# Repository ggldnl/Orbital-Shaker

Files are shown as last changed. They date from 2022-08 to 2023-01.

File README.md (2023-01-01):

# Orbital Shaker

I needed something to help me out shaking the ferric chloride, sodium carbonate and acetone trays when making PCBs. You can check out [my guide](https://github.com/ggldnl/pcb_manufacturing.git) to manufacture PCBs at home. It ain't much but it's honest work

This project was born as a sort of remix of [this orbital shaker](https://learn.adafruit.com/crickit-lab-shaker/3d-printing) to adapt the hardware to what I had at the time at hands; I got caught up in it and added many features via software, hardware and redesigning most of the cad files in fusion360, so I think it is safe to say that this is now a project on its own. 

# Contributing and warn for possible bugs
There will probably still be small bugs (surely one in the soft start menu item), feel free to contribute in any way.
As soon as I have time I will rewrite the code from scratch by implementing the menu in my own way and without resorting to external libraries. Another thing to do would be to use custom (maybe animated) characters (https://www.engineersgarage.com/making-custom-characters-on-lcd-using-arduino/).

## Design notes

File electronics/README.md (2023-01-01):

# Electronics

| component | quantity |
|---|---|
| LM2596 DCDC step down | 2 |
| DRV8833 | 1 |
| Arduino nano | 1 |
| 10K Potentiometer | 1 |
| Push button | 3 |
| 1K Resistor | 3 |
| Diode | 1 |
| 16x2 LCD Display | 1 |

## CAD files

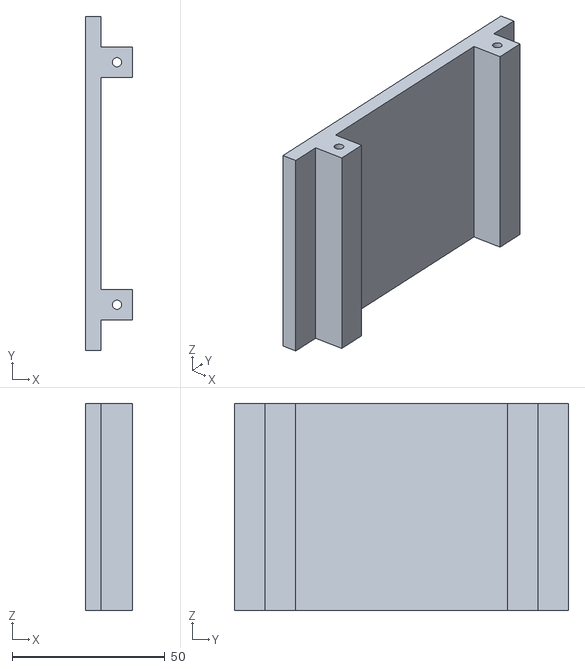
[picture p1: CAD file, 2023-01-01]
cad/left_panel.stl
15.2 x 109.5 x 68.0

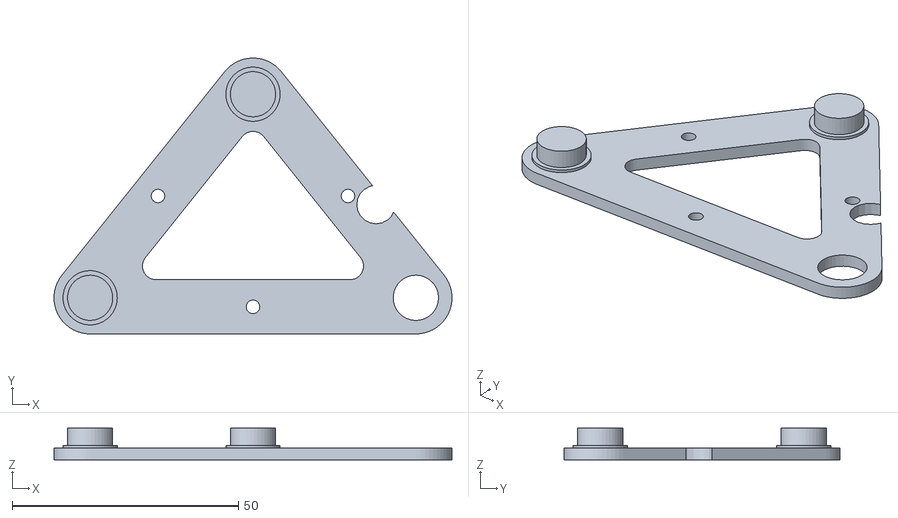
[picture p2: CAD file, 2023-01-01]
cad/bearing_base.stl
88.0 x 61.0 x 7.00

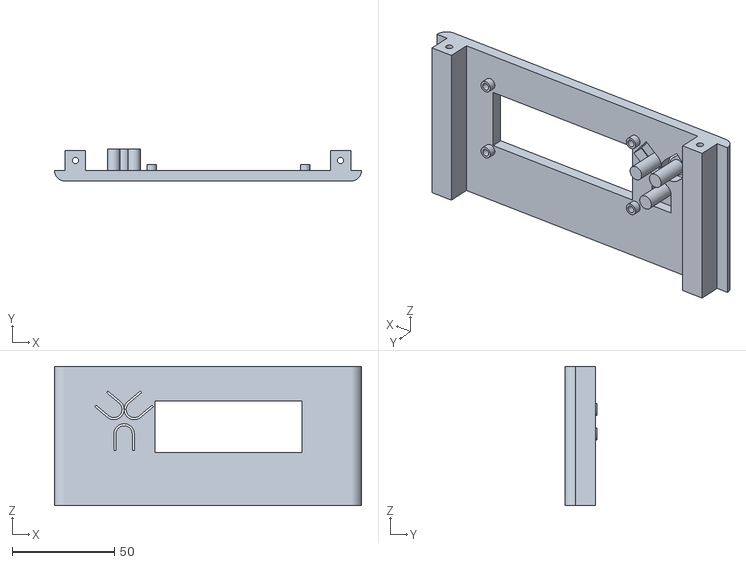
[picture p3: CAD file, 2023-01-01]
cad/front_panel.stl
150.0 x 15.6 x 68.0

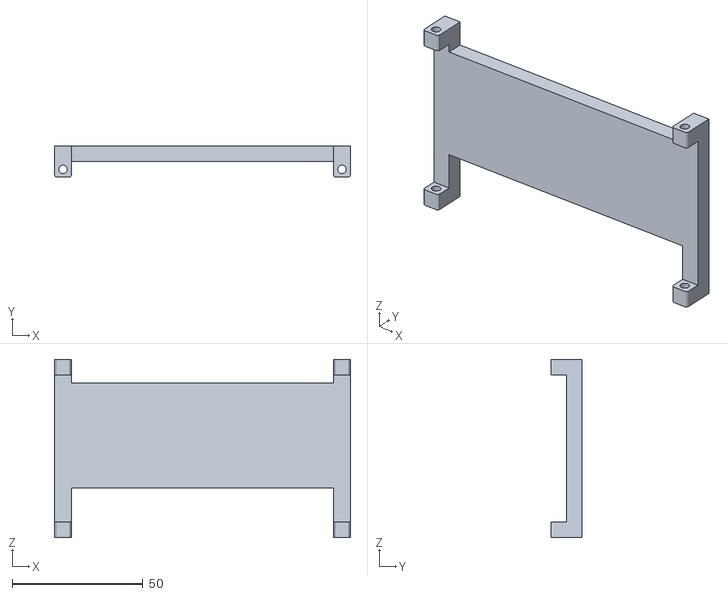
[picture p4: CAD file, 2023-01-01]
cad/display_support.stl
113.0 x 12.0 x 68.0

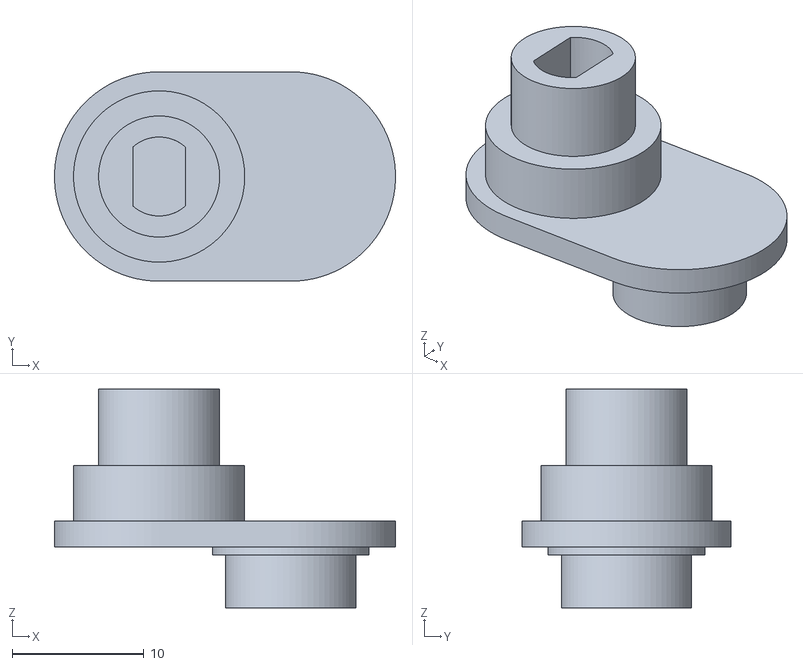
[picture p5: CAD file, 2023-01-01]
cad/motor_hub.stl
25.9 x 15.9 x 16.6

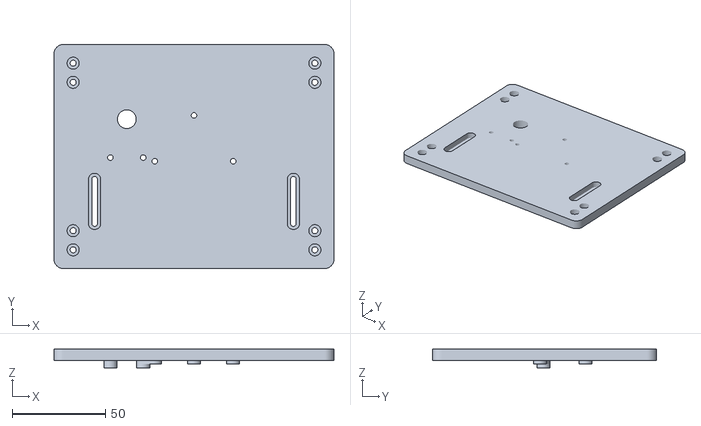
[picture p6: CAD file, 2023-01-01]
cad/top_panel.stl
150.0 x 120.0 x 10.0

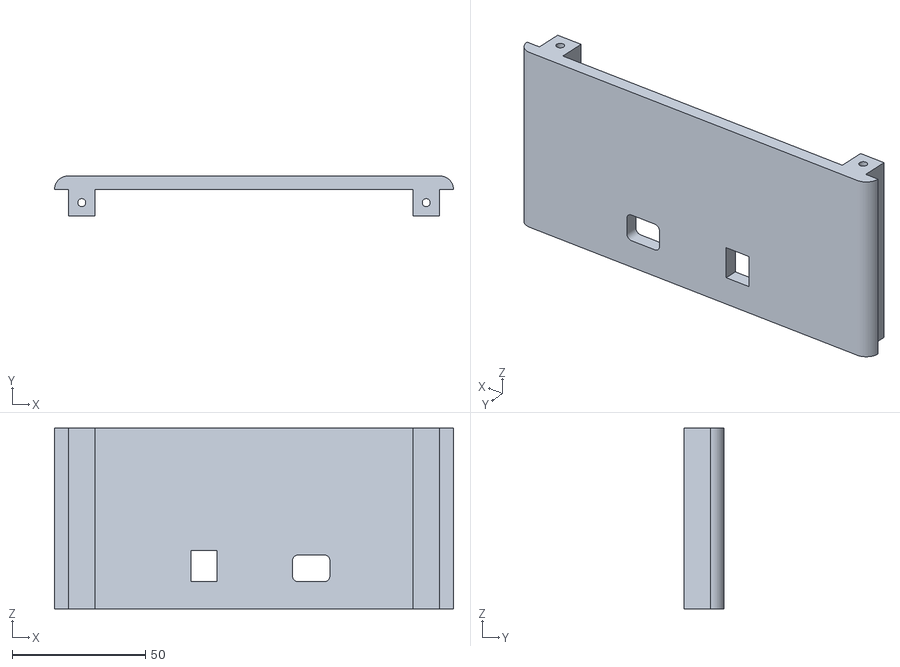
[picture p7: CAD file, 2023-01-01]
cad/back_panel_no_button.stl
150.0 x 15.0 x 68.0

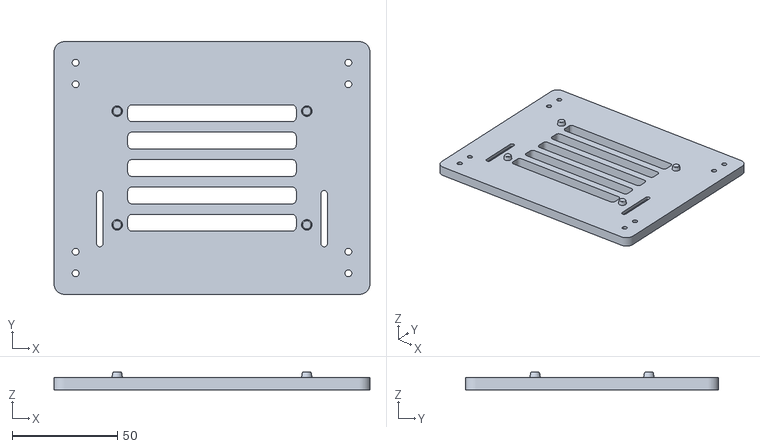
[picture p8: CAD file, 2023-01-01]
cad/bottom_panel.stl
150.0 x 120.0 x 8.50

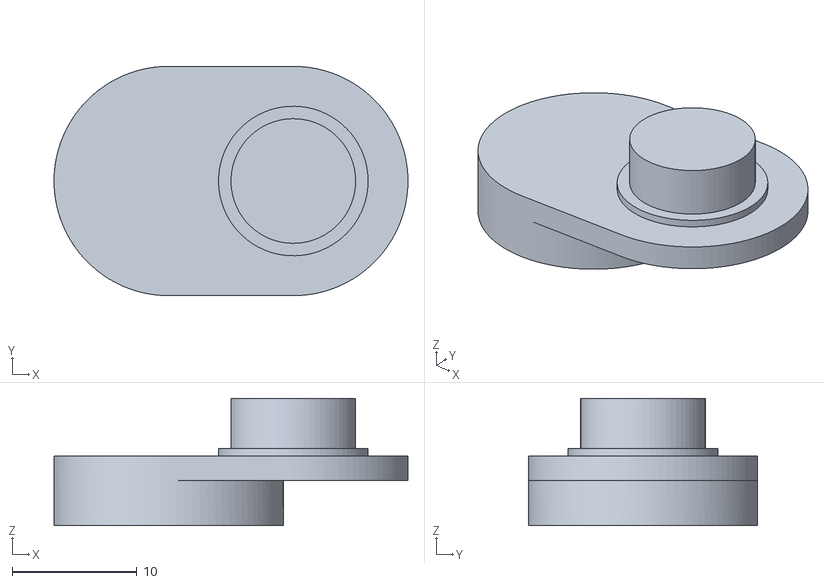
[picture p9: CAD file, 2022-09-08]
cad/idler.stl
28.4 x 18.4 x 10.2

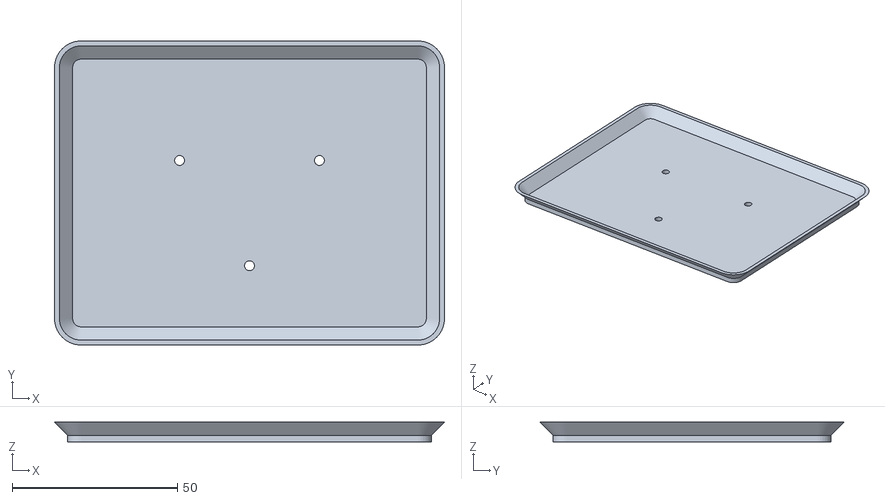
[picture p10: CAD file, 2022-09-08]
cad/tray.stl
118.0 x 92.0 x 6.00

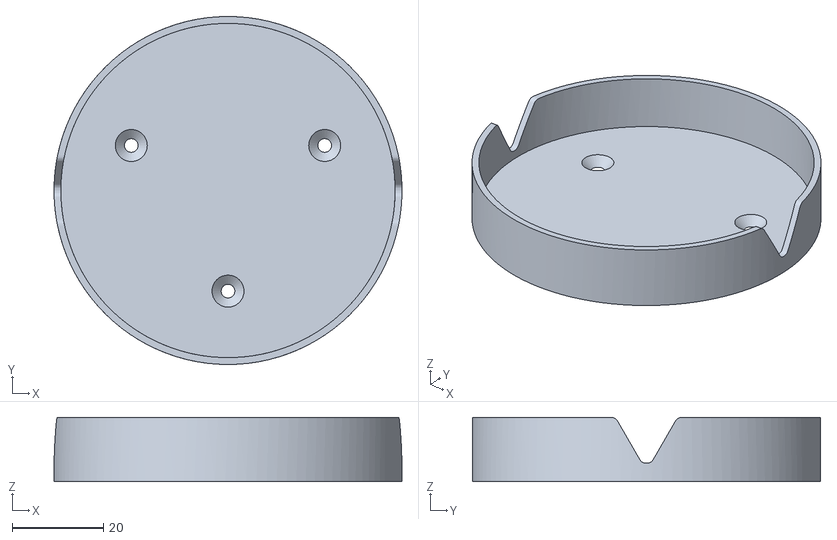
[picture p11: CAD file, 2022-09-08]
cad/holder.stl
76.1 x 76.1 x 14.0

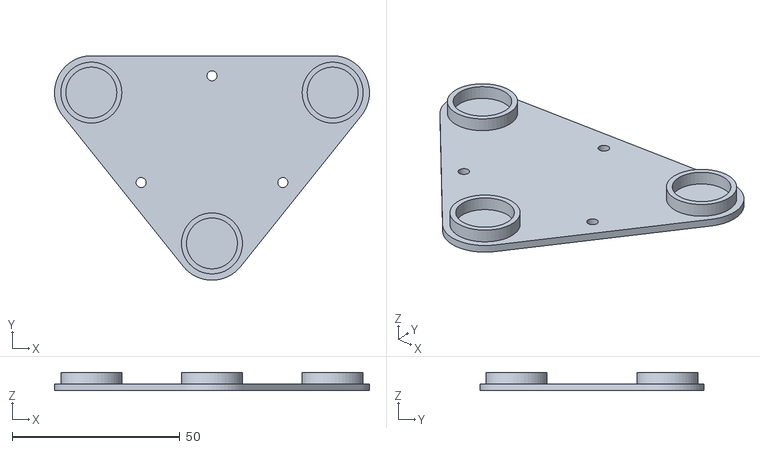
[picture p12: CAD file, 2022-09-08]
cad/plate.stl
94.0 x 67.0 x 5.50

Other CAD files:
cad/right_panel.stl
cad/back_panel_button.stl

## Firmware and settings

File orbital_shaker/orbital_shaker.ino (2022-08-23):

//
// GNU General Public License v3.0
//
// Copyright (C) 2022 Daniel Gigliotti
//
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
/* --------------------------------- pinout --------------------------------- */

/**
 * pins needed for the 1602A LCD screen
 * 
 * VSS -> GND
 * VDD -> +5v
 * V0 -> al potenziometro
 * RS -> D13
 * R/W -> GND
 * E -> A1
 * D0 -> N/C
 * D1 -> N/C
 * D2 -> N/C
 * D3 -> N/C
 * D4 -> Arduino D12
 * D5 -> Arduino D10
 * D6 -> Arduino D9
 * D7 -> Arduino D8
 * A -> Arduino A0
 * K -> GND
 */
#define LCD_RS 13
#define LCD_E  A1
#define LCD_D4 12
#define LCD_D5 11
#define LCD_D6 8
#define LCD_D7 7
#define LCD_A A0

/**
 * we will need 3 push buttons
 * BTN_ENTER -> D4
 * ENC_LEFT -> D5
 * ENC_RIGHT -> D6
 */
#define BTN_ENTER 3
#define BTN_LEFT 4
#define BTN_RIGHT 5
#define PIN_CTRL 6

/**
 * And we will need two PWM pins to drive the motor.
 * The board will be always enabled when current is supplied
 * DRV8833_EEP -> 5V
 * DRV8833_IN1 -> D3
 * DRV8833_IN2 -> D11
 */
#define DRV8833_IN1 10
#define DRV8833_IN2 9

/* -------------------------------- libraries ------------------------------- */

#include <LiquidCrystal.h> // for the LCD
#include "CMBMenu.hpp"

// timer to handle the routine, explained later in mainStart(...) function
#include <Simpletimer.h>

/*
 * Library developed by Kalinin Edward
 * http://mypractic.com/ 
 * Lesson 18. 
 * 
 * I only added a method to check if a pin is enabled or not
 */
#include "MatrixKey.h"
#include <MsTimer2.h> // to use the MatrixKey library: it updates the status periodically

/*
 * Library developed by *me* :)
 */
#include "DRV8833.h"

/* --------------------------------- objects -------------------------------- */

LiquidCrystal lcd(LCD_RS, LCD_E, LCD_D4, LCD_D5, LCD_D6, LCD_D7);

// vertical line -> pin 7
// horizontal line -> 4, 5, 6
// number of confirmations of the status of contacts = 6
MatrixKeys keys (PIN_CTRL, 255, 255, 255, BTN_ENTER, BTN_LEFT, BTN_RIGHT, 255, 6);

DRV8833 motor_driver (DRV8833_IN1, DRV8833_IN2);

/* ---------------------------------- menu ---------------------------------- */

// create global CMBMenu instance
CMBMenu<100> menu; // max 100 menu entries

/**
 * the menu will have this structure:
 *   initial_screen
 *    back
 *    settings
 *      back
 *      speed
 *      time
 *      change direction (y/n)
 *    start
 */
// PROGMEM -> store the string  into the flash memory
const char main_menu_str[] PROGMEM = {"Orbital Shaker"};
const char main_settings_str[] PROGMEM = {"Settings"};
const char main_start_str[] PROGMEM = {"Start"};
const char settings_speed_str[] PROGMEM = {"Speed"};
const char settings_time_str[] PROGMEM = {"Time"};
const char settings_direction_str[] PROGMEM = {"Change dir"};
const char settings_dir_interval_str[] PROGMEM = {"Change dir int."};
const char settings_soft_start_str[] PROGMEM = {"Soft start"};
const char main_info_str[] PROGMEM = {"Info"};
const char back_str[] PROGMEM = {"Back"};

// define function IDs
enum MenuFID {
  MainMenu,
  MainBack,
  MainSettings,
  MainStart,
  MainInfo,
  SettingsBack,
  SettingsSpeed,
  SettingsTime,
  SettingsDir,
  SettingsDirInterval,
  SettingsSoftStart
};

// define key types
enum KeyType {
  KeyNone, // no key is pressed
  KeyLeft,
  KeyRight,
  KeyEnter
};

void setup_lcd (void) {
  
  pinMode(LCD_A, OUTPUT); // A0
  digitalWrite(LCD_A, HIGH); // LCD turned on

  pinMode(A1, OUTPUT); // E (enable)
  digitalWrite(A1, HIGH);

  // (rows, cols)
  lcd.begin(16, 2);

  delay(500);
  lcd.print("Sup bitch");
  delay(1000);
  lcd.clear();
}

void setup_keypad (void) {
  MsTimer2::set(2, timerInterrupt); // set the timer interrupt period 2 ms
  MsTimer2::start(); // enable timer interrupt  
}

void setup_motor_driver (void) {
  motor_driver.hardware_setup(); // All done inside the library, poor design choices YOLOOOO
}

void timerInterrupt() {
  keys.scanState(); // scan matrix
}

/* -------------------------------- variables ------------------------------- */

/*
 * Timer0 is used for micros(), millis(), delay(), etc and can't be used
 * Timer1 is used to generate hardware pwm for the DRV8833 board
 * Timer2 is used for the keypad
 * 
 * since the timing doesn't have to be precise for the routine (the error is in the order of ms,
 * while once the job starts it can last several minutes) we can simply use millis() and so on
 * in the main loop to check if the job needs to be terminated or not.
 * The library SimpleTimer internally uses millis() and micros()
 */
bool job_running = false;
long running_time = 0;
Simpletimer jobTimer; // timer to handle the whole procedure

const int update_interval = 1000; // 1000 ms
long starting_time = 0;
long elapsed_time = 0;
long job_percent = 0;
Simpletimer lcdUpdateTimer; // timer to update the percentage on the lcd

// job duration
int time_m = 10; // standard job duration
int time_delta = 1;
int min_time = 1;
int max_time = 60;

// speed
int current_speed = 50;
const int speed_delta = 10;
int min_speed = 10;
int max_speed = 100;

// soft start
Simpletimer softStartTimer; // timer to increase speed for a soft start
bool soft_start = true;
int soft_start_speed = 10;
int soft_start_delta = 5;

// change direction
Simpletimer changeDirTimer; // timer to periodically change direction
bool change_dir = true;
int min_dir_interval = 1; // 1 minute
int change_dir_delta = 1;
long change_dir_interval = min_dir_interval;

void setup() {
  
  // open the serial line
  Serial.begin(115200);

  // setup all the stuff
  setup_lcd();
  setup_keypad();
  setup_motor_driver();

  // add nodes to menu (layer, string, function ID)
  menu.addNode(0, main_menu_str , MainMenu);
  menu.addNode(1, main_start_str, MainStart);
  menu.addNode(1, main_settings_str, MainSettings);
  menu.addNode(2, settings_time_str, SettingsTime);
  menu.addNode(2, settings_speed_str, SettingsSpeed);
  menu.addNode(2, settings_direction_str, SettingsDir);
  menu.addNode(2, settings_dir_interval_str, SettingsDirInterval);
  menu.addNode(2, settings_soft_start_str, SettingsSoftStart);
  menu.addNode(2, back_str, SettingsBack);
  menu.addNode(1, back_str, MainBack);
  menu.addNode(1, main_info_str, MainInfo);

  // build menu
  const char* info;
  menu.buildMenu(info);

  // print current menu entry
  printMenuEntry(info);
}

void loop() {

  // function ID
  int fid = 0;

  // info text from menu
  const char* info;

  // go to deeper or upper layer?
  bool layerChanged = false;

  // determine pressed key
  KeyType key = getKey();

  // call menu methods regarding pressed key
  switch(key) {
    case KeyEnter:
      menu.enter(layerChanged);
      break;
    case KeyRight:
      menu.right();
      break;
    case KeyLeft:
      menu.left();
      break;
    default:
      break;
  }

  // pint/update menu when key was pressed
  // and get current function ID "fid"
  if (key != KeyNone) {
    fid = menu.getInfo(info);
    printMenuEntry(info);
  }

  // do action regarding function ID "fid"

  if ((fid != 0) && (KeyEnter == key) && (!layerChanged)) {
    switch (fid) {
      
      case MainBack:
      case SettingsBack:

        back(info);
        break;

      case MainStart:
        mainStart(info);
        break;

      case SettingsSpeed:

        /*
         * we are now stuck in another cycle until enter is pressed again
         */
        settingsSpeed (info);
        break;

      case SettingsTime:

        settingsTime (info);
        break;

      case SettingsDir:

        settingsDir (info);
        break;

      case SettingsSoftStart:

        settingsSoftStart(info);
        break;

      case SettingsDirInterval:

        settingsDirInterval(info);
        break;

      case MainInfo:

        mainInfo (info);
        break;

      default:
        break;
    }
  }

  if (job_running && jobTimer.timer(running_time)){
    callback();
    job_running = false;
    printLines("Job done", "100 %");
    keys.enable();
    
    Serial.print("Job ended after ");
    Serial.print(running_time / 1000);
    Serial.println(" milliseconds");
  }

  /*
   * soft start starts from min speed and increases it until reaching
   * user input speed
   */
  if (job_running && soft_start && softStartTimer.timer(1000)) {
    if (soft_start_speed + soft_start_delta <= current_speed) {
      soft_start_speed += soft_start_delta;
      motor_driver.set_speed(soft_start_speed);

      Serial.print("Speed increased: ");
      Serial.print(soft_start_speed);
      Serial.print(" -> ");
      Serial.print(current_speed);
      Serial.println();
    }
  }

  if (job_running && lcdUpdateTimer.timer(update_interval)) {
    // percent : 100 = elapsed : total
    // percent = (elapsed * 100) / total
    // total = running_time
    elapsed_time = millis() - starting_time;
    job_percent = (elapsed_time * 100) / running_time;
    printLines("Job running...", String(job_percent) + " %");

    Serial.print("Elapsed time: ");
    Serial.print(elapsed_time);
    Serial.println(" ms");

    //Serial.print("Current job percent: ");
    //Serial.print(job_percent);
    //Serial.println(" %");
  }

  if (job_running && change_dir && changeDirTimer.timer(change_dir_interval * 60 * 1000)) {
    motor_driver.halt();
    delay(500); // so the motor doesn't complain
    motor_driver.invert_direction();

    Serial.println("Swapping direction");
  }
}

/* ---------------------------- utility functions --------------------------- */

/*
 * prints the menu entry on the LCD display
 */
void printMenuEntry(const char* f_Info) {

  String info_s;
  MBHelper::stringFromPgm(f_Info, info_s);

  // print on LCD
  lcd.clear();
  lcd.setCursor(0, 0);
  lcd.print(info_s);
}

KeyType getKey() {
  
  KeyType key = KeyNone;

  // MatrixKeys keys (PIN_CTRL, 255, 255, 255, BTN_ENTER, BTN_LEFT, BTN_RIGHT, 255, 6);
  // BTN_ENTER -> 0
  // BTN_LEFT -> 1
  // BTN_RIGHT -> 2
  if (keys.flagClick[0][0] == true) {
    keys.flagClick[0][0] = false; // consume the click
    key = KeyEnter;
    Serial.println("Pressed: Enter");
  } else if (keys.flagClick[0][1] == true) {
    keys.flagClick[0][1] = false;
    key = KeyLeft;
    Serial.println("Pressed: Left");
  } else if (keys.flagClick[0][2] == true) {
    keys.flagClick[0][2] = false;
    key = KeyRight;
    Serial.println("Pressed: Right");
  }

 return key;
}

/*
 * clears the lcd and prints the strings, one on each line
 */
void printLines (String str1, String str2) {
  
  lcd.clear();
  lcd.setCursor(0, 0);
  lcd.print(str1);
  lcd.setCursor(0, 1);
  lcd.print(str2);  
}

void printLines (String str, int value) {

  lcd.clear();
  lcd.setCursor(0, 0);
  lcd.print(str);
  lcd.setCursor(0, 1);
  lcd.print(value);
}

/* ----------------------------- menu functions ----------------------------- */

void back (const char*& info) {
  
  // if the action is "back", then go back duh wtf
  menu.exit();
  
  // update the menu
  menu.getInfo(info);
  printMenuEntry(info);
}

void mainInfo(const char*& info) {

  printLines("Info", ">:( go away");

}

/*
 * TODO: store the speed
 */
void settingsSpeed(const char*& info) {

  printLines("Select speed:", current_speed);

  // determine pressed key
  KeyType key;

  while ((key = getKey()) != KeyEnter) {

    if (key == KeyLeft && current_speed - speed_delta >= min_speed) {
      current_speed -= speed_delta;
      printLines("Select speed:", current_speed);
    } else if (key == KeyRight && current_speed + speed_delta <= max_speed) {
      current_speed += speed_delta;
      printLines("Select speed:", current_speed);
    }
  }

  Serial.print("Speed set to ");
  Serial.print(current_speed);
  Serial.println(" %");

  /*
   * at low speed the plate can't move
   */
  current_speed = map(current_speed, min_speed, max_speed, 40, 100);
  
  back(info); // go back and update the menu
}

/*
 * set the spinning time (minutes); 
 * min = 1 minute
 * max = 60 minutes
 * 
 * TODO: store the duration
 */
void settingsTime(const char*& info) {

  printLines("Select time (m):", time_m);

  // determine pressed key
  KeyType key;

  while ((key = getKey()) != KeyEnter) {

    if (key == KeyLeft && time_m - time_delta >= min_time ) {
      time_m-= time_delta;
      printLines("Select time (m):", time_m);
    } else if (key == KeyRight && time_m + time_delta <= max_time) {
      time_m += time_delta;
      printLines("Select time (m):", time_m);
    }
  }

  Serial.print("Time set to ");
  Serial.print(time_m);
  Serial.println(" minute(s)");

  back(info); // go back and update the menu
}

/*
 * change spinning direction each n seconds (default every minute)
 * 
 */
void settingsDir(const char*& info) {

  printLines("Change dir?", change_dir ? "YES" : "NO");

  // determine pressed key
  KeyType key;

  while ((key = getKey()) != KeyEnter) {
    if (key == KeyLeft && change_dir == false) {
      change_dir = true;
      printLines("Change dir?", "YES");
    } else if (key == KeyRight && change_dir == true) {
      change_dir = false;
      printLines("Change dir?", "NO");
    }
  }

  Serial.print("Change dir?");
  Serial.println(change_dir ? "YES" : "NO");

  back(info); // go back and update the menu
}

/*
 * change direction periodically every n minutes/seconds
 */
void settingsDirInterval(const char*& info) {

  printLines("Select interval (m):", change_dir_interval);

  // determine pressed key
  KeyType key;

  while ((key = getKey()) != KeyEnter) {

    if (key == KeyLeft && change_dir_interval - change_dir_delta >= min_dir_interval ) {
      change_dir_interval -= change_dir_delta;
      printLines("Select interval (m):", change_dir_interval);
    } else if (key == KeyRight && change_dir_interval + change_dir_delta <= time_m) {
      change_dir_interval += change_dir_delta;
      printLines("Select time (m):", change_dir_interval);
    }
  }

  Serial.print("Swapping time set to ");
  Serial.print(change_dir_interval);
  Serial.println(" minute(s)");

  back(info); // go back and update the menu
}

/*
 * starts with low speed and slowly increase it
 */
void settingsSoftStart(const char*& info) {

  printLines("Soft start?", soft_start ? "YES" : "NO");

  // determine pressed key
  KeyType key;

  while ((key = getKey()) != KeyEnter) {
    if (key == KeyLeft && soft_start == false) {
      soft_start = true;
      printLines("Soft start", "YES");
    } else if (key == KeyRight && soft_start == true) {
      soft_start = false;
      printLines("Soft start", "NO");
    }
  }

  Serial.print("Soft start?");
  Serial.println(soft_start ? "YES" : "NO");

  back(info); // go back and update the menu
}

void callback(){
  motor_driver.halt();
}

void mainStart (const char*& info) {

  job_running = true;
  running_time = 60 * (long)time_m * 1000; // ms
  starting_time = millis();

  keys.disable();

  if (soft_start)
    motor_driver.forward(current_speed);
  else
    motor_driver.forward(min_speed);
  
  Serial.print("Starting job (");
  Serial.print(running_time);
  Serial.println(") ms");
}

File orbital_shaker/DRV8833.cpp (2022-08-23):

#include "DRV8833.h"
#include <TimerOne.h> // PWM generation
#include "Arduino.h"

DRV8833::DRV8833 (int IN_1, int IN_2, int EEP):
  _IN_1(IN_1), _IN_2(IN_2), _EEP(EEP) {}

DRV8833::DRV8833 (int IN_1, int IN_2):
  _IN_1(IN_1), _IN_2(IN_2), _EEP(255) {}

/*
 * forward:
 * 1   pwm   forward, slow decay
 * pwm   0   forward, fast decay
 */
void DRV8833::forward (float speed_percent) {

  _input_speed = speed_percent;
  _pwm = get_pwm(speed_percent);
  _direction = Direction::FORWARD;

  if (this -> _decay_mode == Decay::SLOW_DECAY) {
    digitalWrite(_IN_1, HIGH);
    Timer1.pwm(_IN_2, _pwm);
  } else {
    Timer1.pwm(_IN_1, _pwm);
    digitalWrite(_IN_2, LOW);
  }
}

/*
 * bacward:
 * pwm   1   backward, slow decay
 * 0   pwm   backward, fast decay
 */
void DRV8833::backward (float speed_percent) {

  _input_speed = speed_percent;
  _pwm = get_pwm(speed_percent);
  _direction = Direction::BACKWARD;

  if (this -> _decay_mode == Decay::SLOW_DECAY) {
    Timer1.pwm(_IN_1, _pwm);
    digitalWrite(_IN_2, HIGH);
  } else {
    digitalWrite(_IN_2, LOW);
    Timer1.pwm(_IN_2, _pwm);
  }
}

void DRV8833::halt () {

  Timer1.pwm(_IN_1, 0);
  Timer1.pwm(_IN_2, 0);
}

void DRV8833::set_slow_decay () {
  _decay_mode = Decay::SLOW_DECAY;
}

void DRV8833::set_fast_decay () {
  _decay_mode = Decay::FAST_DECAY;
}

void DRV8833::set_speed (float new_speed) {
  if (_direction == Direction::BACKWARD)
    backward(new_speed);
  else
    forward(new_speed);
}

void DRV8833::invert_direction () {
  if (_input_speed != 0)
    if (_direction == Direction::BACKWARD)
      forward(_input_speed);
    else
      backward(_input_speed);
}

void DRV8833::hardware_setup () {

  // enable the board
  if (_EEP != 255) {
    pinMode(_EEP, OUTPUT);
    digitalWrite (_EEP, HIGH); 
  }

  pinMode(_IN_1, OUTPUT);
  pinMode(_IN_2, OUTPUT);

  Timer1.initialize(40);

}

int DRV8833::get_pwm (float speed_percent) {

  /* 
   * speed = 0 used to stop the motors
   * but a speed value between 0 and the threshold should be ignored
   */
  if (speed_percent == 0.0)
    return 0;

  /*
   * clamp the value in range (threshold, 100)
   */
  if (speed_percent > 100.0)
    speed_percent = 100.0;

  if (speed_percent < _speed_threshold)
    speed_percent = _speed_threshold;

  // speed : 100 = x : 1024
  // x = (speed * 1024) / 100;
  float new_speed = 100.0 - speed_percent;

  return (new_speed * 1023) / 100;
}

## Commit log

2022-08-22 lcd works, menu works, keypad works; need to complete DRV8833 drivers
2022-08-23 almost done; still some bugs with pwm generation for the DRV8833, need testing to understand its behaviour
    [DRV8833.cpp, MatrixKey.cpp, orbital_shaker.ino]
2022-09-08 added some STLs
    [shaker-holder-circular.stl, shaker-idler.stl, shaker-plate.stl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]
2022-09-11 meh good point now imma sleep
    [shaker-body-back.stl, shaker-body-bottom.stl, shaker-body-front.stl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]

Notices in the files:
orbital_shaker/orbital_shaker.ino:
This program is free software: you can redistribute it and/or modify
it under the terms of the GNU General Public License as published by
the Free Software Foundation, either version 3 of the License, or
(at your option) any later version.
